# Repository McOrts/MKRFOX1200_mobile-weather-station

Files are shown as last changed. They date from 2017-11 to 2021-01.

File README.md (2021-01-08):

# Mobile IOT weather station based on Arduino MKRFOX1200
The arduino MKRFOX1200 with connection to Sigfox has taken the democratization of the use of microcontrollers to the space of the IOT and the cloud.

Based on this microprocessor **I build a mobile weather station for UV, pressure and temperature measures in anywhere**. This compact device can collect environment information each 15 minutes autonomously for three months with three AA batteries and almost anywhere in the world. 

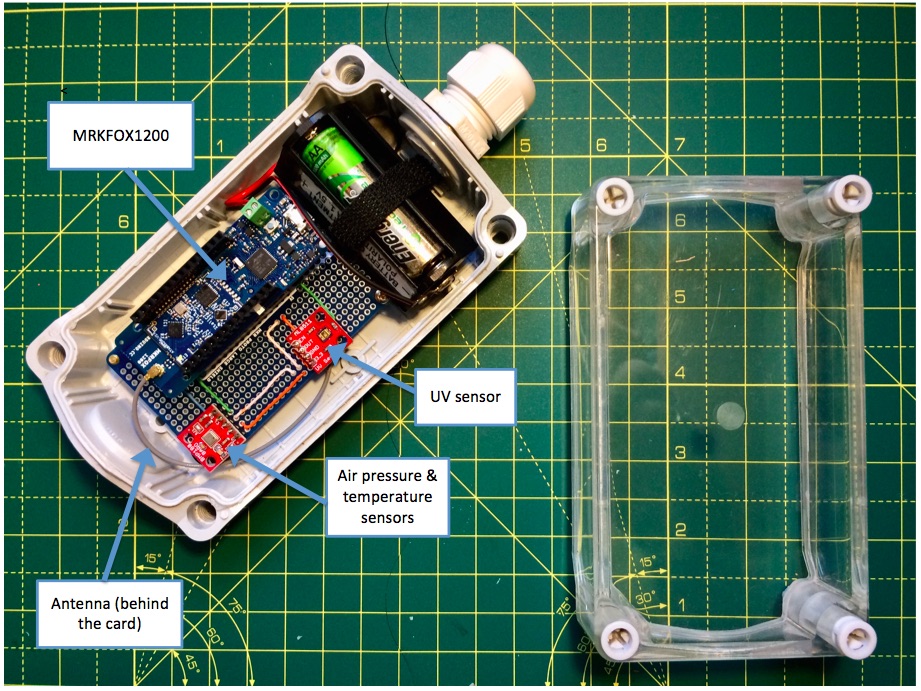
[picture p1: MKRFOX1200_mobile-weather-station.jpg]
MKRFOX1200_mobile-weather-station

The device is finally **placed on the beach of Palma de Mallorca in Spain**. So you can see right now the index of ultraviolet radiation, temperature and atmospheric pressure in the following link: https://thingspeak.com/channels/365024

This project will put on your cell phone the basic weather information collected in real time by a mobile device that you can "abandon" in a large part of the world.

## IOT Concept

The Internet of Things is a network of connected devices which communicate over the Internet, and they do so autonomously, machine to machine, without the need for human intervention.

> The first reference to the IoT was in 1982, when researchers at Carnegie Mellon University developed the world’s first IoT-enabled Coke Machine. Mark Weiser developed the concept further in the early 90s; and Kevin Ashton coined the term ‘Internet of Things’ around 1999.

All IOT architecture is built with 5 components. I will list these components explaining the implementation I have made to build this device.

### Sensors
The world can be watched with a large array of sensors to choose from. Today they are invisible and energy efficient, whilst maintaining a high measurement precision. I used these:
* [ML8511](https://learn.sparkfun.com/tutorials/ml8511-uv-sensor-hookup-guide) Ultra violet sensor
* [BMP180](https://www.adafruit.com/product/1603) Temperature and pressure sensors

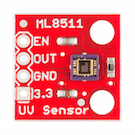
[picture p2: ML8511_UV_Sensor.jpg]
ML8511

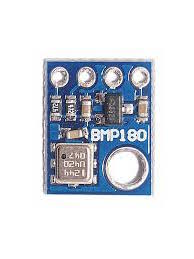
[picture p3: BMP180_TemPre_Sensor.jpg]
BMP180


### Connectivity
Once we have the sensons, we need to connect it reliably to the Internet. But now, wireless connectivity is central to the success of the IoT
Here Sigfox opens the door to connectivity to inaccessible areas for other technologies such as 3 / 4G, GSM or Wifi.
It uses a free frequency band that in Europe is 868 MHz and in the United States it is 915 MHz. It is a narrow band connection that allows very low energy consumption.
The transmission limits are 140 messages per day of no more than 24 bytes. If we divide the 140 messages between 24 hours a day, we have to send a message every 10.2 minutes. This is an example of a sent frame:

```
Frame:			
  4b594e40|0e|00fa|314204740

Decoded values:
  3.2242|14|1018|3.111333
  Battery|Temperature|Presure|UV
```

Additionally, it offers a localization service  based on a proprietary probabilistic calculation of the most probable location of the device. This approach allows for the first release of the service to have an accuracy in km (between 1km and 10km for 80% of devices) depending on the base station density where the device is located. This accuracy will be improved through further releases thanks to machine learning.

This is the global coverage of the sigfox network:

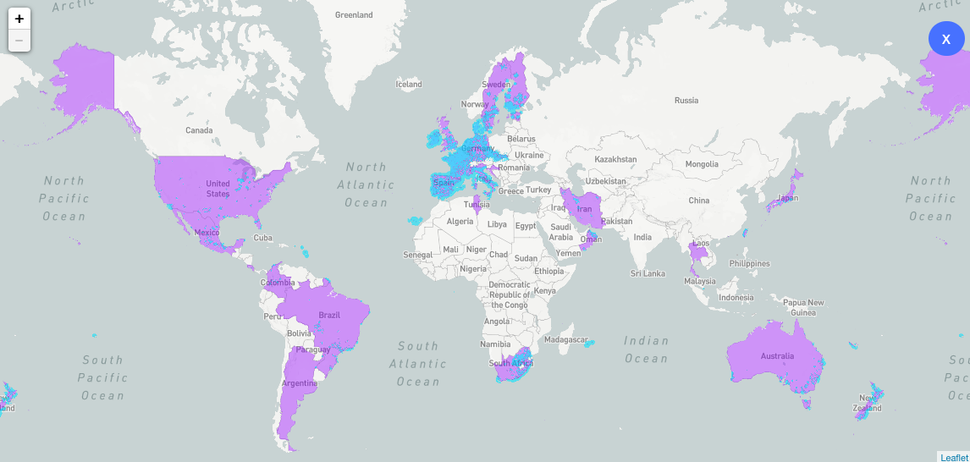
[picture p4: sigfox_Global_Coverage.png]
https://www.sigfox.com/en/coverage


On my Christmas holidays I had the opportunity to try out the device in the different cities that I have visited: Madrid, Salamanca, Warsaw and Krakow. Also It was a few days above the level of 1000m in the Sierra de Tramuntana (Mallorca). All the information collected can be found at: (https://github.com/McOrts/MKRFOX1200_mobile-weather-station/tree/master/MKRFOX1200_mobile-weather-station_report-data)

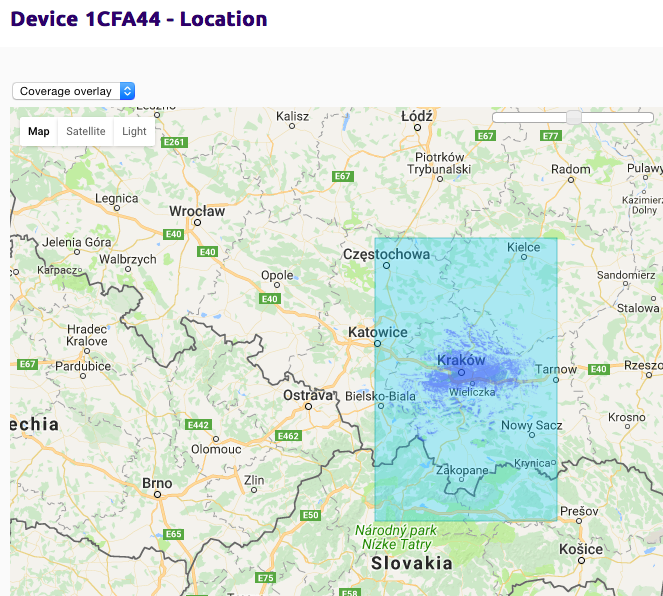
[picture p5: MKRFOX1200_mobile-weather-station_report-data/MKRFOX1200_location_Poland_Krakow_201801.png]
Example of my device location


### Platform
Third, the collected data needs to be stored and processed somewhere. Known as IoT platforms, these are typically cloud-based infrastructures which:

1. receive and send data via standardised interfaces, known as API;
2. store the data; and
3. process the data.

For this project I chose [ThingSpeak](https://thingspeak.com). platform. A free account allows you to store up to 8 fields as long as the limit of 3,000 bytes is not exceeded with a maximum of 3 million messages per year.

### Analytics
Some data analytics needs to be applied to the data as the value is not in the raw bits and bytes, but rather in the insights gathered from them.

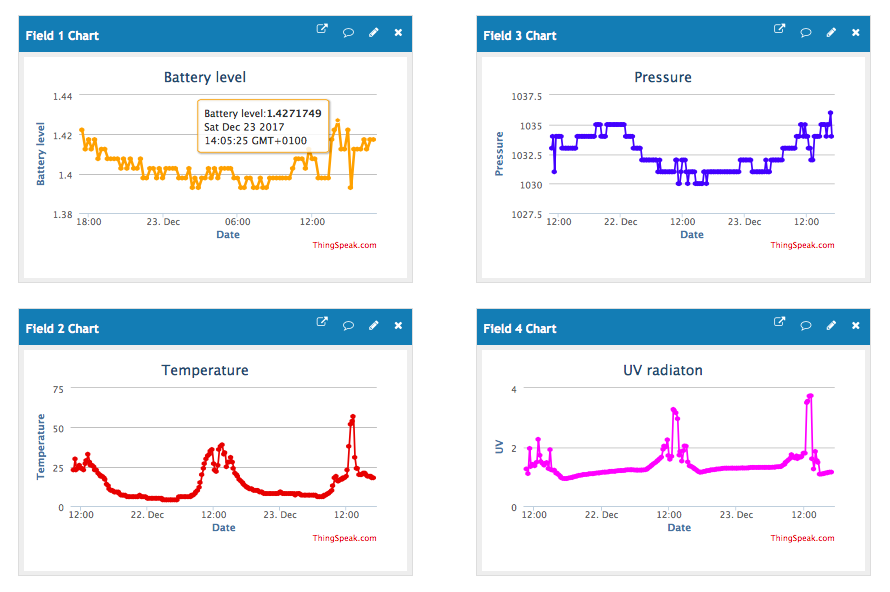
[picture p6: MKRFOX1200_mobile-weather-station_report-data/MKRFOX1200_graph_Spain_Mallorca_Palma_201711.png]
Mallorca data


[ThingSpeak Visualizations](https://thingspeak.com/channels/365024) can not only show graphs of your data. Also can do an analysis of your data using MATLAB programming. For example, calculate the dew point based on temperature and humidity. 

```
% Humidity and temperature are read from a ThingSpeak channel to calculate
% dew point.

% Channel ID to read data from
readChannelID = 365024;
% Humidity Field ID
HumidityFieldID = 2;
% Temperature Field ID
TemperatureFieldID = 3;

% Channel Read API Key 
readAPIKey = 'UTVU9A464TKW6UQ5';

% TODO - Replace the [] with channel ID to write data to:
writeChannelID = 365024;
% TODO - Enter the Write API Key between the '' below:
writeAPIKey = '****************';

tempF = thingSpeakRead(readChannelID, 'Fields', TemperatureFieldID, 'ReadKey', readAPIKey);

% Get latest humidity data from the MathWorks Weather Station channel
humidity = thingSpeakRead(readChannelID, 'Fields', HumidityFieldID, 'ReadKey', readAPIKey);

% Convert temperature from Fahrenheit to Celsius
tempC = (5/9)*(tempF-32);

% Calculate dew point
% Specify the constants for water vapor (b) and barometric (c) pressure.
b = 17.62;
c = 243.5;
% Calculate the intermediate value 'gamma'
gamma = log(humidity/100) + b*tempC ./ (c+tempC);
% Calculate dew point in Celsius
dewPoint = c*gamma ./ (b-gamma);
% Convert to dew point in Fahrenheit
dewPointF = (dewPoint*1.8) + 32;
display(dewPointF, 'Dew point')

% Write the dew point value to another channel specified by the
% 'writeChannelID' variable

thingSpeakWrite(writeChannelID, dewPointF, 'Writekey', writeAPIKey);

```
In addition, ThingSpeak allows you to  act on the data by triggering events such as twitter messages.

### User Interface
An important component is how the data is presented to the final users. There are appealing user interfaces, both web based as well as smart phone or tablet based. 

I have chosen an application that offers a widget in iOS:

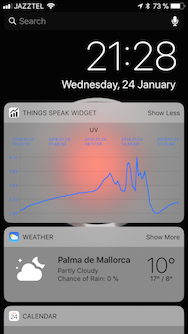
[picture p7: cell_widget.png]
Widget app with UV measure


## Schematic and Connections
I assembled all the components for the prototype over a [MKR Proto Large Shield](https://store.arduino.cc/mkr-proto-large-shield). This is the breadboard:

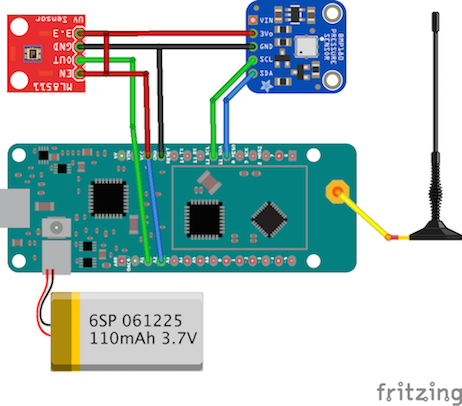
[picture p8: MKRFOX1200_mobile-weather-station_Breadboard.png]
Breadboard


## Architecture
This device collects environmental data and send the information as a discrete radio packets each 15 minutes. The radio network ingests the data in internet network through rest-api calls. So finally, websites and mobile applications can process and display de information. 

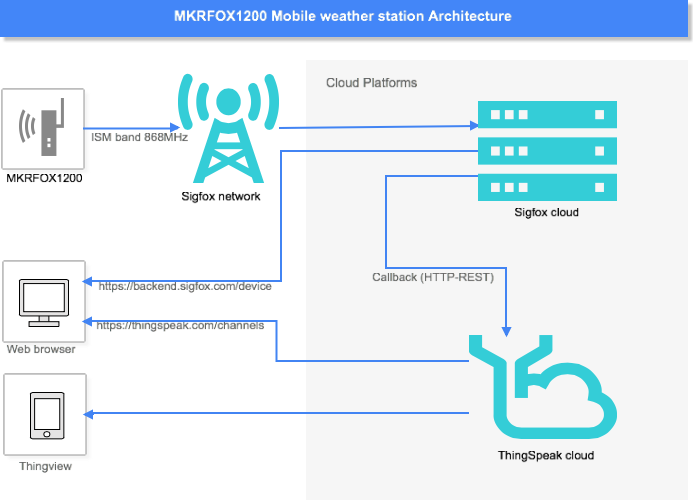
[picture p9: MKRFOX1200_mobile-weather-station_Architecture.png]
Architecture


## Acknowledgements
To Luis del Valle of https://programarfacil.com for the blog entry:
(https://programarfacil.com/podcast/sigfox-arduino-mkrfox1200-radiacion-uv/)

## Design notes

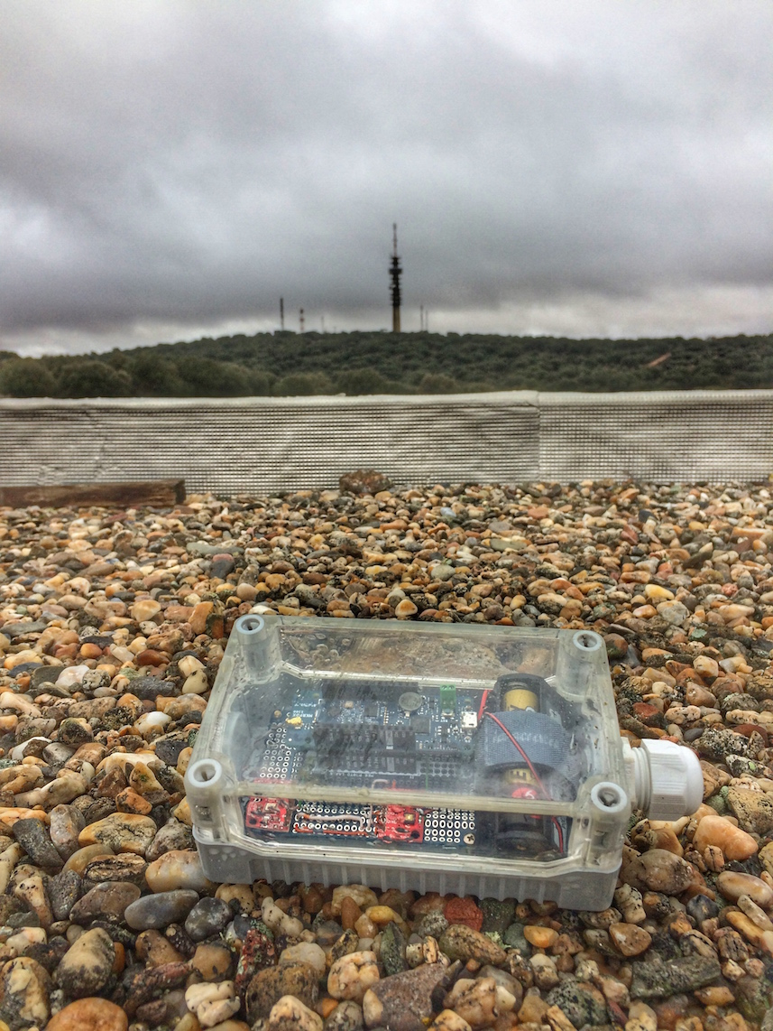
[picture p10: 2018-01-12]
MKRFOX1200_mobile-weather-station_report-data/MKRFOX1200_picture_Spain_Salamanca_Montalvos_201712.JPG

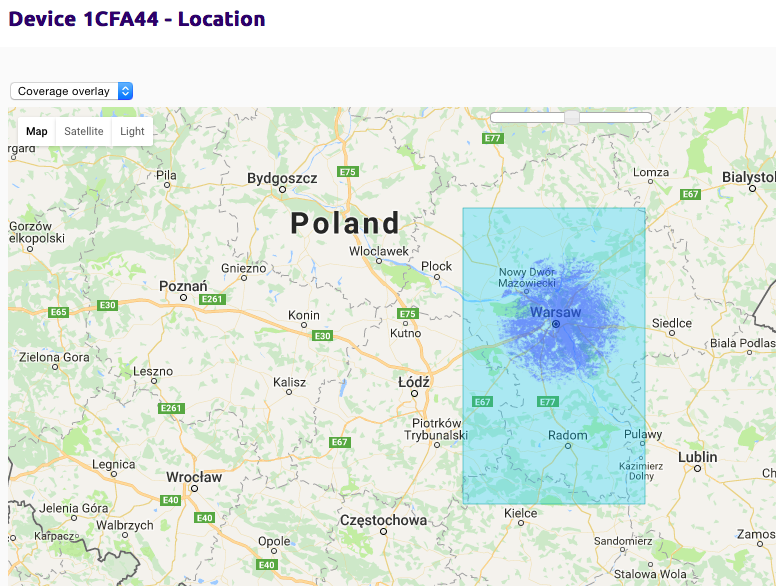
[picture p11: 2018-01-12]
MKRFOX1200_mobile-weather-station_report-data/MKRFOX1200_location_Poland_Warsaw_201801.png

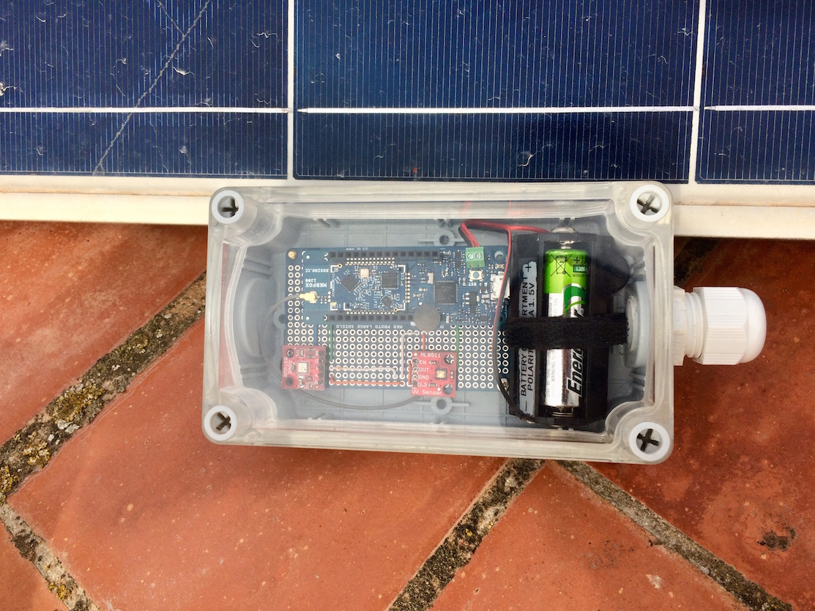
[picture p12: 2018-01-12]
MKRFOX1200_mobile-weather-station_report-data/MKRFOX1200_picture_Spain_Mallorca_Palma_201711.jpg

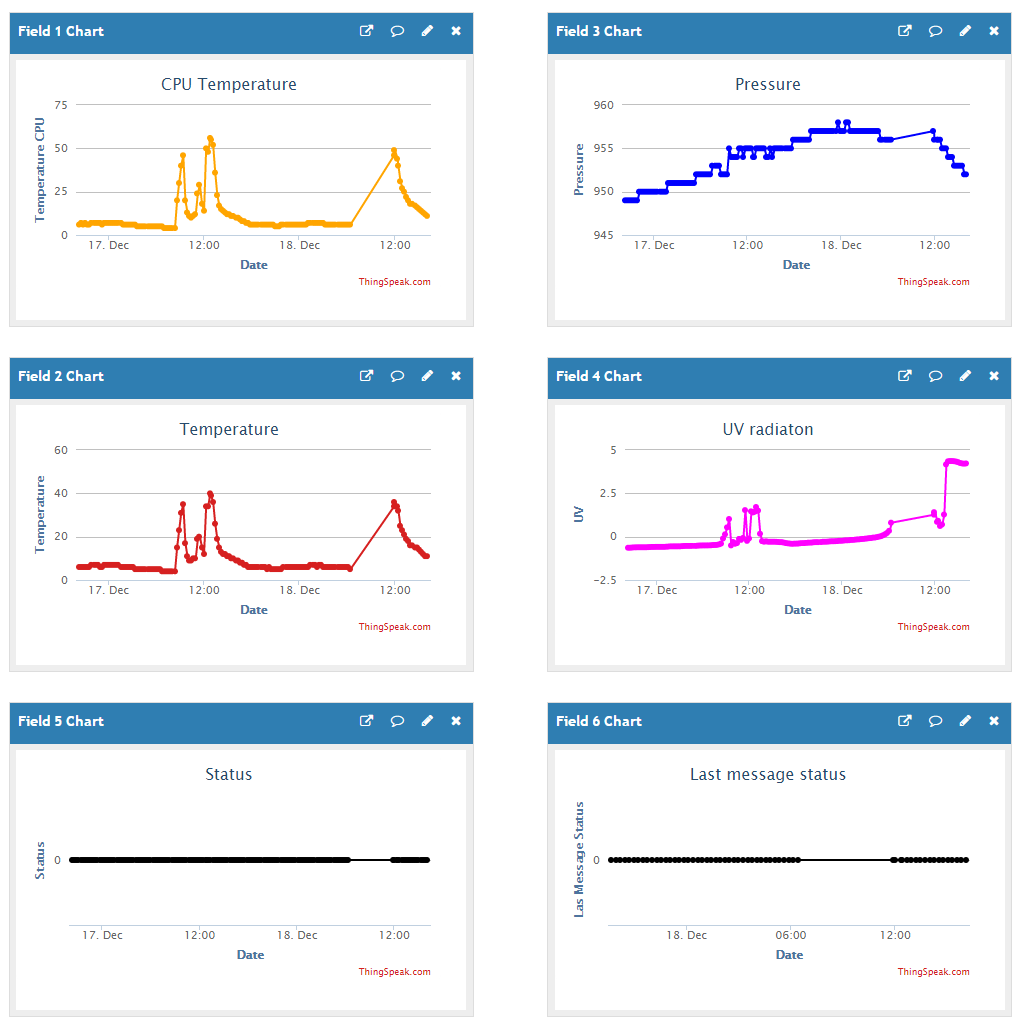
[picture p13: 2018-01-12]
MKRFOX1200_mobile-weather-station_report-data/MKRFOX1200_graph_Spain_Mallorca_Tramuntana_201712.png

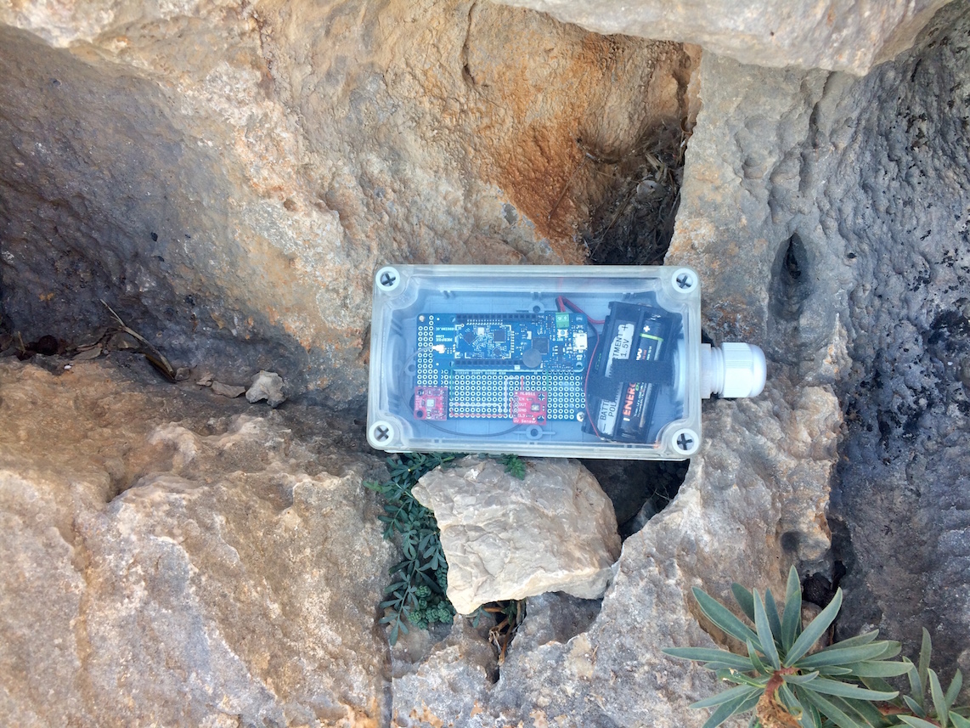
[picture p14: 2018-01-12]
MKRFOX1200_mobile-weather-station_report-data/MKRFOX1200_picture_Spain_Mallorca_Tramuntana_201712.JPG

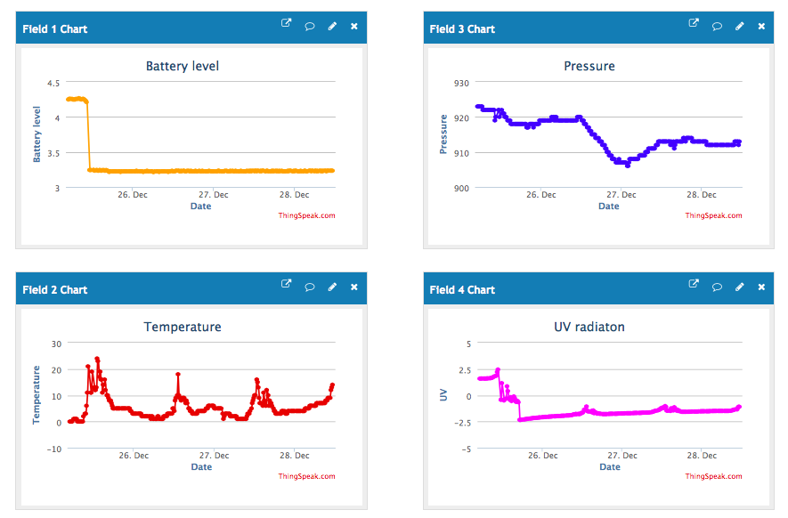
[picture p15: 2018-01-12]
MKRFOX1200_mobile-weather-station_report-data/MKRFOX1200_graph_Spain_Salamanca_Montalvos_201712.png

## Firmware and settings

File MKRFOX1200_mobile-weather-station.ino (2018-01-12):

/*
  SigFox Mobile weather station
  This example code is in the public domain.
*/
// Descomentar para hacer debug
#define DEBUG_SIGFOX 1

// libraries
#include <SFE_BMP180.h>
#include <Wire.h>
#include <ArduinoLowPower.h>
#include <SigFox.h>

// Sensor de temperatura y presión
const int numBmp180 = 50; // Número de muestras
SFE_BMP180 bmp180;
float temps[numBmp180]; // Array para almacenar lecturas
int tempActual = 0; // Lectura por la que vamos
float tempTotal = 0; // Total de las que llevamos
float tempMedia = 0; // Media de las medidas
bool tempPrimera = false; // Para saber que ya hemos calculado por lo menos una

float presis[numBmp180]; // Array para almacenar lecturas
float presisTotal = 0; // Total de las que llevamos
float presisMedia = 0; // Media de las medidas

// Sensor de UV
int UVOUT = A1; // Entrada del sensor
int REF_3V3 = A2; // Entrada de referencia 3,3V

const int numUv = 50; // Número de muestras
float uvs[numUv]; // Array para almacenar lecturas
int uvActual = 0; // Lectura por la que vamos
float uvTotal = 0; // Total de las que llevamos
float uvMedia = 0; // Media de las medidas
bool uvPrimera = false; // Para saber que ya hemos calculado por lo menos una

// Sensor de interno de temperatura
// float CPUtemp = 0; // Temperatura en el momemnto

// Sensor de interno de voltaje
 float BatteryLevel = 0;

// Estructura para almacenar datos
typedef struct __attribute__ ((packed)) sigfox_message {
  // int16_t sigfoxTemperature;
  float mrkBatteryLevel;
  int16_t bmpTemperature;
  uint16_t bmpPressure;
  float sparkUv;
  uint8_t status;
  uint8_t lastMessageStatus;
} SigfoxMessage;

SigfoxMessage msg;

// Centinela para saber cuando transmitir 10 minutos mínimo tomando muestras
bool empiezaTransmitir = false;
unsigned long tiempoInicial = 0;
unsigned long tiempoEstimado = 5 * 60 * 1000; //5 minutos

void setup() {
  Serial.println("void setup");
#ifdef DEBUG_SIGFOX
  Serial.begin(9600);
#endif
  /********* Sigfox ************/
  if (!SigFox.begin()) {
    // Something is really wrong, try rebooting
    // Reboot is useful if we are powering the board using an unreliable power source
    // (eg. solar panels or other energy harvesting methods)
    reboot();
  }

  // Ponemos el módulo en estado reposo hasta que mandemos el mensaje
  SigFox.end();

  Serial.println("iniciando BMP180");
  /************ SETUP BMP180 **************/
  // Iniciamos el sensor de temperatura y presión
  if (bmp180.begin())
  {
#ifdef DEBUG_SIGFOX
    Serial.println("BMP180 iniciado");
#endif
  }
  else
  {
    Serial.println("BMP180 ha fallado\n\n");
#ifdef DEBUG_SIGFOX
    // Algo ha ido mal
    Serial.println("BMP180 ha fallado\n\n");
#endif
    while (1); // Bucle infinito.
  }

  // Inicializamos el array media temperatura y presión
  for (int i = 0; i < numBmp180; i++)
  {
    temps[i] = 0;
    presis[i] = 0;
  }

  // Inicializamos el array media radiación UV
  for (int i = 0; i < numUv; i++)
  {
    uvs[i] = 0;
  }

  /********* SETUP UV ************/
  pinMode(UVOUT, INPUT);
  pinMode(REF_3V3, INPUT);

  // Debugamos Sigfox
  SigFox.debug();

  // Obtenemos el tiempo inicial
  tiempoInicial = millis();
}

void loop() {
  // read the input on analog pin 0:
  float BatteryLevel = analogRead(ADC_BATTERY) * 3.76 / 400;
  
  // Medir temperatura
  medirTemp();
  // Medir radiación UV
  medirUV();

  // Si ha pasado el tiempo establecido marcamos para empezar a transmitir
  if (millis() - tiempoInicial >= tiempoEstimado)
  {
    empiezaTransmitir = true;
  }

  // Comprobamos que tengamos todas las medidas y que haya pasado el tiempo estimado
  if (uvPrimera && tempPrimera && empiezaTransmitir)
  {

    // Start the module
    SigFox.begin();
    // Wait at least 30ms after first configuration (100ms before)
    delay(100);

    // We can only read the module temperature before SigFox.end()
    // CPUtemp = SigFox.internalTemperature();

    // Almacenamos la información para enviar
    // msg.sigfoxTemperature = CPUtemp;
    msg.mrkBatteryLevel = BatteryLevel;
    msg.bmpTemperature = tempMedia;
    msg.bmpPressure = presisMedia;
    msg.sparkUv = uvMedia;

#ifdef DEBUG_SIGFOX
    Serial.begin(9600);
    //Serial.print("CPU temperature: ");
    //Serial.println(CPUtemp, 2);
    Serial.print("Battery level V: ");
    Serial.println(BatteryLevel);
    Serial.print("Temperatura: ");
    Serial.print(tempMedia, 2);
    Serial.print(" *C , ");
    Serial.print("Presion: ");
    Serial.print(presisMedia, 2);
    Serial.println(" mb");
    Serial.print("Radiación UV (mW/cm^2): ");
    Serial.println(uvMedia);
    Serial.print("Milisegundos: ");
    Serial.println(millis());
#endif
    // Reseteamos los contadores
    tempPrimera = false;
    uvPrimera = false;
    empiezaTransmitir = false;
    tempActual = 0;
    uvActual = 0;


    // Clears all pending interrupts
    SigFox.status();
    delay(1);

    SigFox.beginPacket();
    SigFox.write((uint8_t*)&msg, 12);

    msg.lastMessageStatus = SigFox.endPacket(true);
#ifdef DEBUG_SIGFOX
    Serial.println("Status: " + String(msg.lastMessageStatus));
#endif

    SigFox.end();

    //A dormir 10 minutos
    LowPower.sleep(10 * 60 * 1000);

    // Empezamos a contar el tiempo
    tiempoInicial = millis();
  }
  else
  {
    delay(200);
  }
}

/*************Sigfox**************/
void reboot() {
  Serial.println("void reboot");
  NVIC_SystemReset();
  while (1);
}

void medirUV()
{
  // Eliminamos la última medida
  uvTotal = uvTotal - uvs[uvActual];

  int uvLevel = averageAnalogRead(UVOUT);
  int refLevel = averageAnalogRead(REF_3V3);

  // Calculo de la radiacion con la referencia de 3,3V
  float outputVoltage = 3.3 / refLevel * uvLevel;
  //Serial.println(refLevel);
  //Serial.println(uvLevel);
  //float outputVoltage = BatteryLevel / refLevel * uvLevel;

  float uvIntensity = mapfloat(outputVoltage, 0.99, 2.8, 0.0, 15.0); // Conversión entre voltaje y radiación UV

  // Almacenamos la distancia en el array
  uvs[uvActual] = uvIntensity;

  // Añadimos la lectura al total
  uvTotal = uvTotal + uvs[uvActual];

  // Avanzamos a la siguiente posición del array
  uvActual = uvActual + 1;

  // Comprobamos si hemos llegado al final del array
  if (uvActual >= numUv)
  {
    uvPrimera = true;
    uvActual = 0;
  }

  // Calculamos la media
  uvMedia = uvTotal / numUv;
}

// Calcula la media de cada pin
int averageAnalogRead(int pinToRead)
{
  byte numberOfReadings = 10;
  unsigned int runningValue = 0;

  for (int x = 0 ; x < numberOfReadings ; x++)
    runningValue += analogRead(pinToRead);
  runningValue /= numberOfReadings;

  return (runningValue);
}

// Función map con floats
//From: http://forum.arduino.cc/index.php?topic=3922.0
float mapfloat(float x, float in_min, float in_max, float out_min, float out_max)
{
  return (x - in_min) * (out_max - out_min) / (in_max - in_min) + out_min;
}

void medirTemp()
{
  char status;
  double T, P;

  // Eliminamos la última medida
  tempTotal = tempTotal - temps[tempActual];
  presisTotal = presisTotal - presis[tempActual];

  status = bmp180.startTemperature(); //Inicio de lectura de temperatura
  if (status != 0)
  {
    delay(status); //Pausa para que finalice la lectura
    status = bmp180.getTemperature(T); //Obtener la temperatura
    if (status != 0)
    {
      status = bmp180.startPressure(3); //Inicio lectura de presión
      if (status != 0)
      {
        delay(status); //Pausa para que finalice la lectura
        status = bmp180.getPressure(P, T); //Obtenemos la presión
        if (status != 0)
        {
          // Almacenamos la temperatura en el array=
          temps[tempActual] = (float)T;
          // Almacenamos la presión en el array
          presis[tempActual] = (float)P;

          // Añadimos la lectura al total
          tempTotal = tempTotal + temps[tempActual];

          // Añadimos la lectura al total
          presisTotal = presisTotal + presis[tempActual];

          // Avanzamos a la siguiente posición del array
          tempActual = tempActual + 1;

          // Comprobamos si hemos llegado al final del array
          if (tempActual >= numBmp180)
          {
            tempPrimera = true;
            tempActual = 0;
          }

          // Calculamos la media
          tempMedia = tempTotal / numBmp180;
          presisMedia = presisTotal / numBmp180;
        }
      }
    }
  }
}

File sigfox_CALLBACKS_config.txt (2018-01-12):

Custom payload config:
battery::float:32:little-endian temp::int:16:little-endian press::uint:16:little-endian uv::float:32:little-endian

Url pattern:
https://api.thingspeak.com/update?api_key=RJERPCCHBS8T3141&field1={customData#battery}&field2={customData#temp}&field3={customData#press}&field4={customData#uv}

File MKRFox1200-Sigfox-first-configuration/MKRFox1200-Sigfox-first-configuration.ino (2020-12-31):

/*

  SigFox First Configuration

  This sketch demonstrates the usage of MKRFox1200 SigFox module.

  Since the board is designed with low power in mind, it depends directly on ArduinoLowPower library

  This example code is in the public domain.

*/

#include <SigFox.h>
#include <ArduinoLowPower.h>

void setup() {

  Serial.begin(9600);

  while (!Serial) {};

  // Uncomment this line and comment begin() if you are working with a custom board

  //if (!SigFox.begin(SPI1, 30, 31, 33, 28, LED_BUILTIN)) {

  if (!SigFox.begin()) {

    Serial.println("Shield error or not present!");

    return;

  }

  // Enable debug led and disable automatic deep sleep

  // Comment this line when shipping your project :)

  SigFox.debug();

  String version = SigFox.SigVersion();

  String ID = SigFox.ID();

  String PAC = SigFox.PAC();

  // Display module informations

  Serial.println("MKRFox1200 Sigfox first configuration");

  Serial.println("SigFox FW version " + version);

  Serial.println("ID  = " + ID);

  Serial.println("PAC = " + PAC);

  Serial.println("");

  Serial.print("Module temperature: ");

  Serial.println(SigFox.internalTemperature());

  Serial.println("Register your board on https://buy.sigfox.com/activate with provided ID and PAC");

  Serial.println("/!\ The displayed PAC is the factory value. It is a throw-away value, which can only be used once for registration.");

  Serial.println("If this device has already been registered, you can retrieve the updated PAC value on https://backend.sigfox.com/device/list");  

  Serial.println("Join the Sigfox Builders Slack community to exchange with other developers, get help .. and find new ideas! https://builders.iotagency.sigfox.com/");

  delay(100);

  // Send the module to the deepest sleep

  SigFox.end();

  Serial.println("Type the message to be sent");

  while (!Serial.available());

  String message;

  while (Serial.available()) {

    message += (char)Serial.read();

  }

  // Every SigFox packet cannot exceed 12 bytes

  // If the string is longer, only the first 12 bytes will be sent

  if (message.length() > 12) {

    Serial.println("Message too long, only first 12 bytes will be sent");

  }

  Serial.println("Sending " + message);

  // Remove EOL

  message.trim();

  // Example of message that can be sent

  // sendString(message);

  Serial.println("Getting the response will take up to 50 seconds");

  Serial.println("The LED will blink while the operation is ongoing");

  // Example of send and read response

  sendStringAndGetResponse(message);
}

void loop()
{
}

void sendString(String str) {

  // Start the module

  SigFox.begin();

  // Wait at least 30mS after first configuration (100mS before)

  delay(100);

  // Clears all pending interrupts

  SigFox.status();

  delay(1);

  SigFox.beginPacket();

  SigFox.print(str);

  int ret = SigFox.endPacket();  // send buffer to SIGFOX network

  if (ret > 0) {

    Serial.println("No transmission");

  } else {

    Serial.println("Transmission ok");

  }

  Serial.println(SigFox.status(SIGFOX));

  Serial.println(SigFox.status(ATMEL));

  SigFox.end();
}

void sendStringAndGetResponse(String str) {

  // Start the module

  SigFox.begin();

  // Wait at least 30mS after first configuration (100mS before)

  delay(100);

  // Clears all pending interrupts

  SigFox.status();

  delay(1);

  SigFox.beginPacket();

  SigFox.print(str);

  int ret = SigFox.endPacket(true);  // send buffer to SIGFOX network and wait for a response

  if (ret > 0) {

    Serial.println("No transmission");

  } else {

    Serial.println("Transmission ok");

  }

  Serial.println(SigFox.status(SIGFOX));

  Serial.println(SigFox.status(ATMEL));

  if (SigFox.parsePacket()) {

    Serial.println("Response from server:");

    while (SigFox.available()) {

      Serial.print("0x");

      Serial.println(SigFox.read(), HEX);

    }

  } else {

    Serial.println("Could not get any response from the server");

    Serial.println("Check the SigFox coverage in your area");

    Serial.println("If you are indoor, check the 20dB coverage or move near a window");

  }

  Serial.println();

  SigFox.end();
}

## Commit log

2017-11-25 Breadboard info files
    [MKRFOX1200_mobile-weather-station_Breadboard.fzz]
2017-11-25 CPU temperature added
2017-12-02 Configuration for SigFox callbacks to ThingSpeak
    [sigfox_CALLBACKS_config.txt]
2017-12-11 Picture of the device
2018-01-12 Battery level
    [sigfox_CALLBACKS_config.txt]
2018-01-12 Minor changes
    [MKRFOX1200_mobile-weather-station_Breadboard.fzz]
2018-01-25 UV, temperature and presure sensons
2018-01-27 Device breadboard
    [MKRFOX1200_mobile-weather-station_Breadboard.fzz]
2018-01-27 Pressure and temperature sensor
2020-12-31 Program to show de ID and PAC
    Mandatory to setup the device in SigFox
